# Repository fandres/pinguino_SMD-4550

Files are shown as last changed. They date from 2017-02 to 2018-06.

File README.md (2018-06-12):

This repository is possibly outdated
Este Repositorio se probablemente se encuentra desactualizado

Repository migrated to https://gitlab.com/fandres323/pinguino_SMD-4550
Repositorio migrado a https://gitlab.com/fandres323/pinguino_SMD-4550

# Pinguino SMD 4550

PCB in surface mount of the Pinguino board based on the microcontroller PIC18F4550 
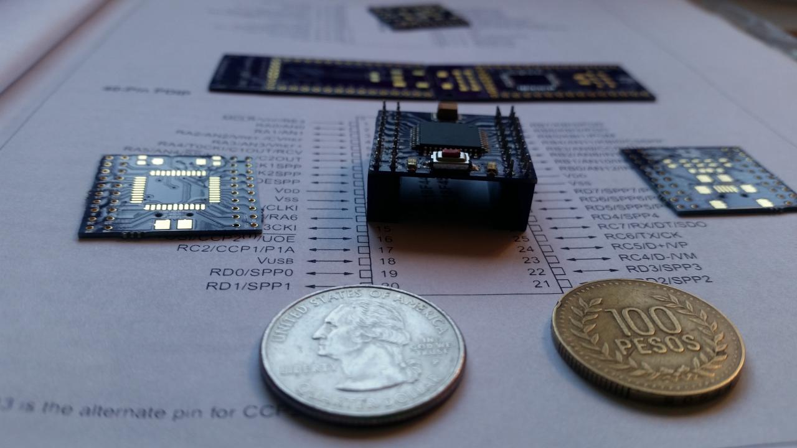
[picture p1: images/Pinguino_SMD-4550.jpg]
Pinguino_SMD-4550


## BOM 
Reference | Qty | Value | Footprint | Package
----- | ---------- | -------- | -------- | --------
C1 C2  | 2 | 22uF | Capacitors_SMD:C_0805 | 0805
C4  | 1 | 220nF | Capacitors_SMD:C_0805 | 0805
C3  | 1 | 100nF | Capacitors_SMD:C_0805 | 0805
C5  | 1 | 10-100uF | Capacitors_Tantalum_SMD:TantalC_SizeB_EIA-3528_Wave | B 3528
D1  | 1 | Run_LED | LEDs:LED_0805 | 0805
D2  | 1 | Power_LED | LEDs:LED_0805 | 0805
P1  | 1 | uUSB | Connect:USB_Mini-B | USB Female mini B 
P2 - P37 | 2 | Socket_Strips:Socket_Strip_Straight_2x10 | Female SIL 10x2 Pin
R2  | 1 | 10k | Resistors_SMD:R_0805 | 0805
R1 R3  | 2 | 470 | Resistors_SMD:R_0805 | 0805
SW1  | 1 | Reset | Buttons_Switches_SMD:SW_SPST_REED_CT05-XXXX-G1 | Sw SMD 1181
U1  | 1 | PIC18(L)F4550-I/PT | Housings_QFP:TQFP-44_10x10mm_Pitch0.8mm | TQFP-44
Y1  | 1 | Crystal | Crystal SMD:Crystal_SMD_5032_2Pads | 5032 2 Pads

# Order from OSH Park, $5 x3 



# Pinguino IDE

http://pinguino.cc/download.php

# Images
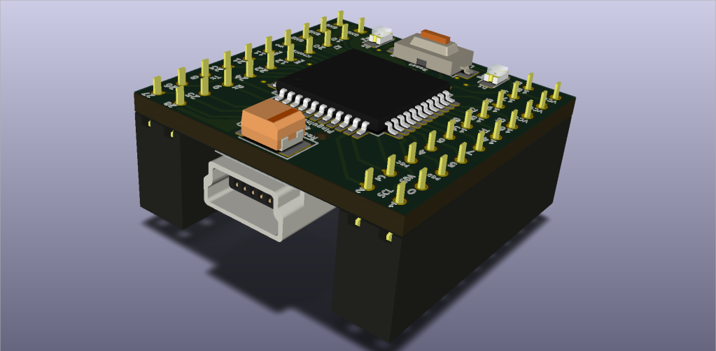
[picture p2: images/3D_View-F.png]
3DF_Pinguino_SMD-4550

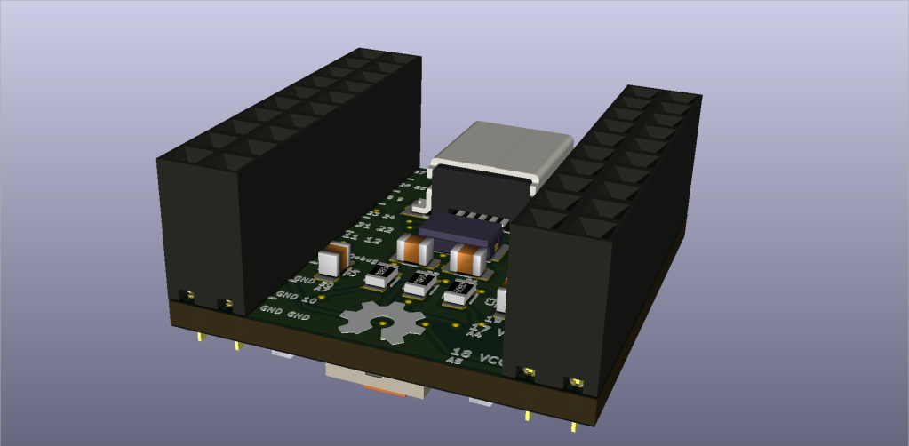
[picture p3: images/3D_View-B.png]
3DB_Pinguino_SMD-4550

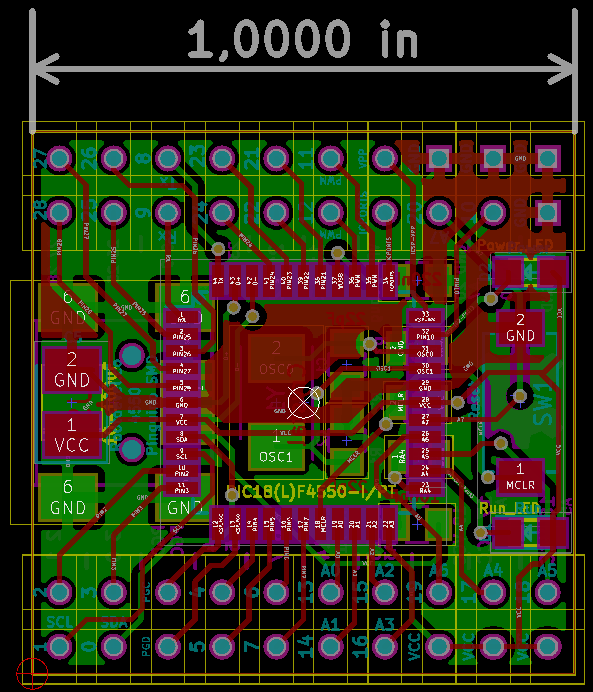
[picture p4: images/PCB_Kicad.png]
PCB_Pinguino_SMD-4550

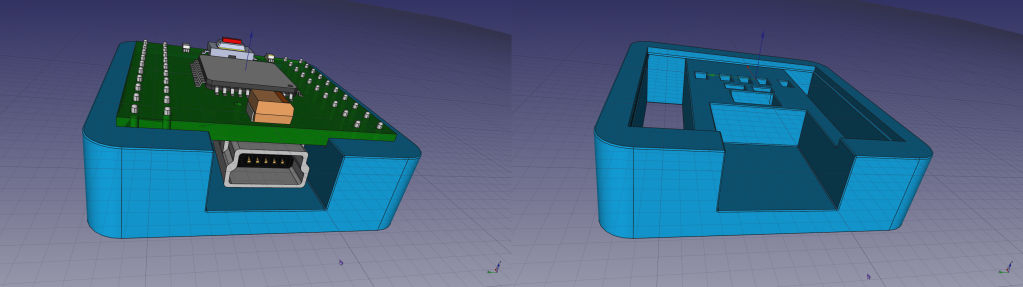
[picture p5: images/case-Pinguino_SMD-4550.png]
Cape_Pinguino_SMD-4550


# Attributions
<br /><span xmlns:dct="http://purl.org/dc/terms/" property="dct:title">Pinguino_SMD-4550</span> por <a xmlns:cc="http://creativecommons.org/ns#" href="https://github.com/fandres/pinguino_SMD-4550" property="cc:attributionName" rel="cc:attributionURL">Fabian Salamanca (fandres)</a> se distribuye bajo una <a rel="license" href="http://creativecommons.org/licenses/by-sa/4.0/">Licencia Creative Commons Atribución-CompartirIgual 4.0 Internacional</a>.<br />Basada en una obra en <a xmlns:dct="http://purl.org/dc/terms/" href="http://www.pinguino.cc/" rel="dct:source">http://www.pinguino.cc/</a>.

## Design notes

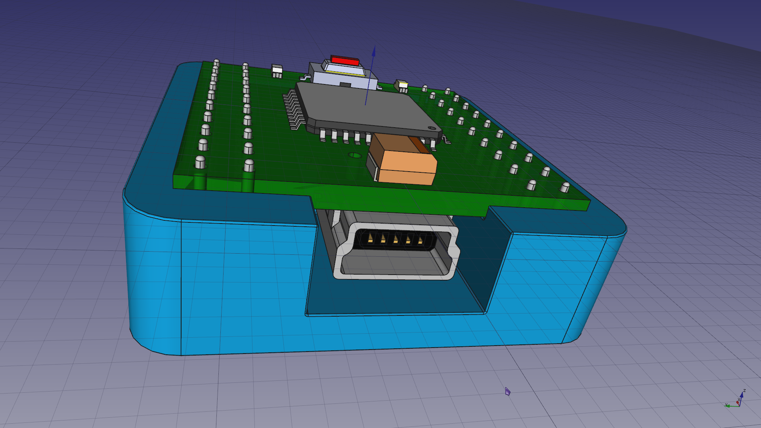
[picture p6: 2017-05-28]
images/case-Pinguino_SMD-4550.png_1.png

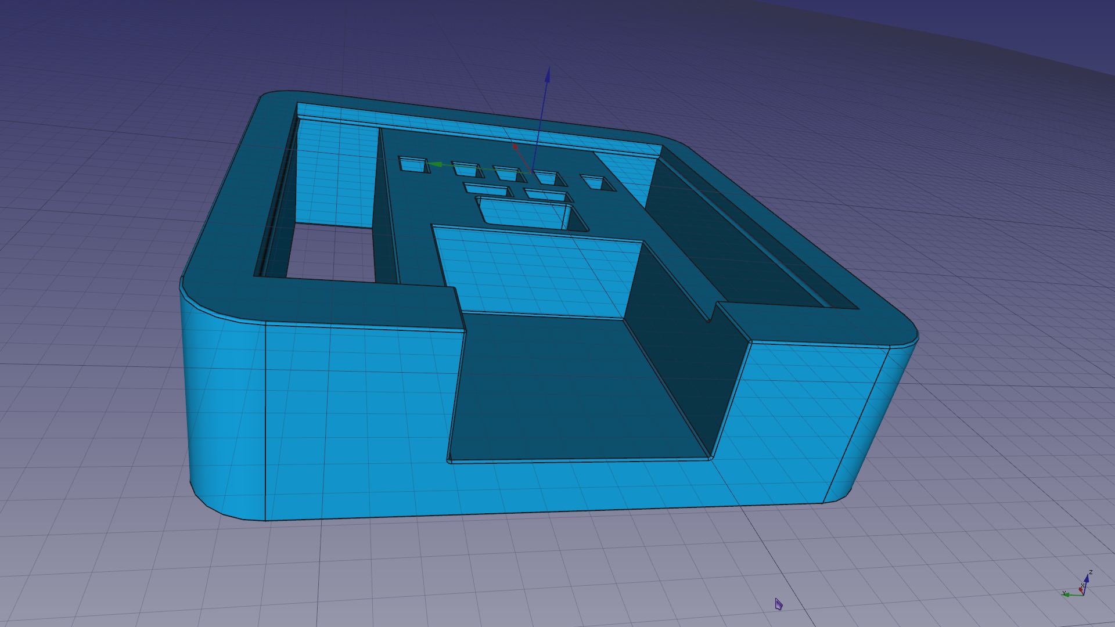
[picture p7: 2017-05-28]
images/case-Pinguino_SMD-4550.png_2.png

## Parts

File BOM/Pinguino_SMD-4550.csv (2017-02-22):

Title | Pinguino_SMD-4550
Revision | 1B
Date
Generated | mar 03 ene 2017 12:07:44 COT
Company | Rottdevel
Comment 1 | Hakerspace
Comment 2 | fAnDrEs
Comment 3
Comment 4
Total Parts | 51
Total Unique Parts | 13
Ref | Qty | Value | Footprint
C1 C2 | 2 | 22uF | Capacitors_SMD:C_1206
C4 | 1 | 220nF | Capacitors_SMD:C_1206
C3 | 1 | 100nF | Capacitors_SMD:C_1206
C5 | 1 | 10-100uF | Capacitors_SMD:c_elec_6.3x5.3
D1 | 1 | Run_LED | LEDs:LED_1206
D2 | 1 | Power_LED | LEDs:LED_1206
P1 | 1 | uUSB | Connect:USB_Mini-B
P6 P7 P9 P11 P13 P15 P17 P19 P21 P23 P25 P27 P29 P31 P33 P8 P10 P12 P14 P16 P34 P32 P30 P28 P26 P24 P22 P20 P18 P35 P36 P37 P4 P2 P5 P3 P38 | 37 | CONN_01X01 | Socket_Strips:Socket_Strip_Straight_1x01
R2 | 1 | 10k | Resistors_SMD:R_1206
R1 R3 | 2 | 470 | Resistors_SMD:R_1206
SW1 | 1 | Reset | Buttons_Switches_SMD:SW_SPST_REED_CT05-XXXX-G1
U1 | 1 | PIC18(L)F4550-I/PT | Housings_QFP:TQFP-44_10x10mm_Pitch0.8mm
Y1 | 1 | Crystal | Crystal SMD:Crystal_SMD_5032_2Pads
BOM made with KICAD_BOM_WIZARD (https://github.com/HashDefineElectronics/KiCad_BOM_Wizard.git)
Generated mar 03 ene 2017 12:07:44 COT

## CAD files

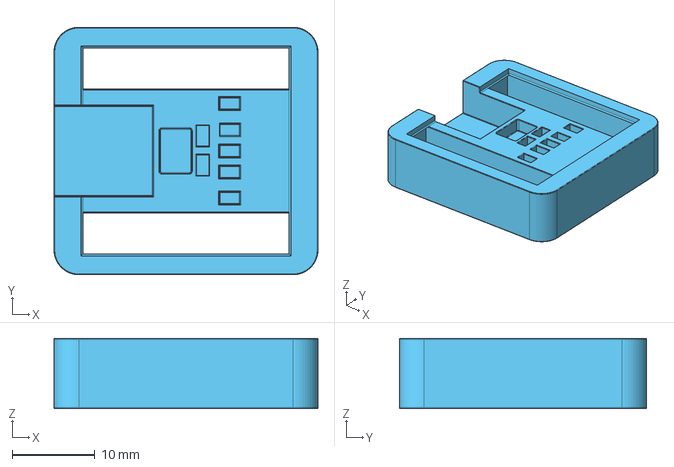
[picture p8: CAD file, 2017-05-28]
3D-Model/case-Pinguino_SMD-4550.step
32.0 x 30.0 x 8.50 mm

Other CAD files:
3D-Model/Pinguino_SMD-4550.step
3D-Model/Pinguino_SMD-4550.stl
3D-Model/Pinguino_SMD_4550.FCStd
3D-Model/case-Pinguino_SMD-4550.stl

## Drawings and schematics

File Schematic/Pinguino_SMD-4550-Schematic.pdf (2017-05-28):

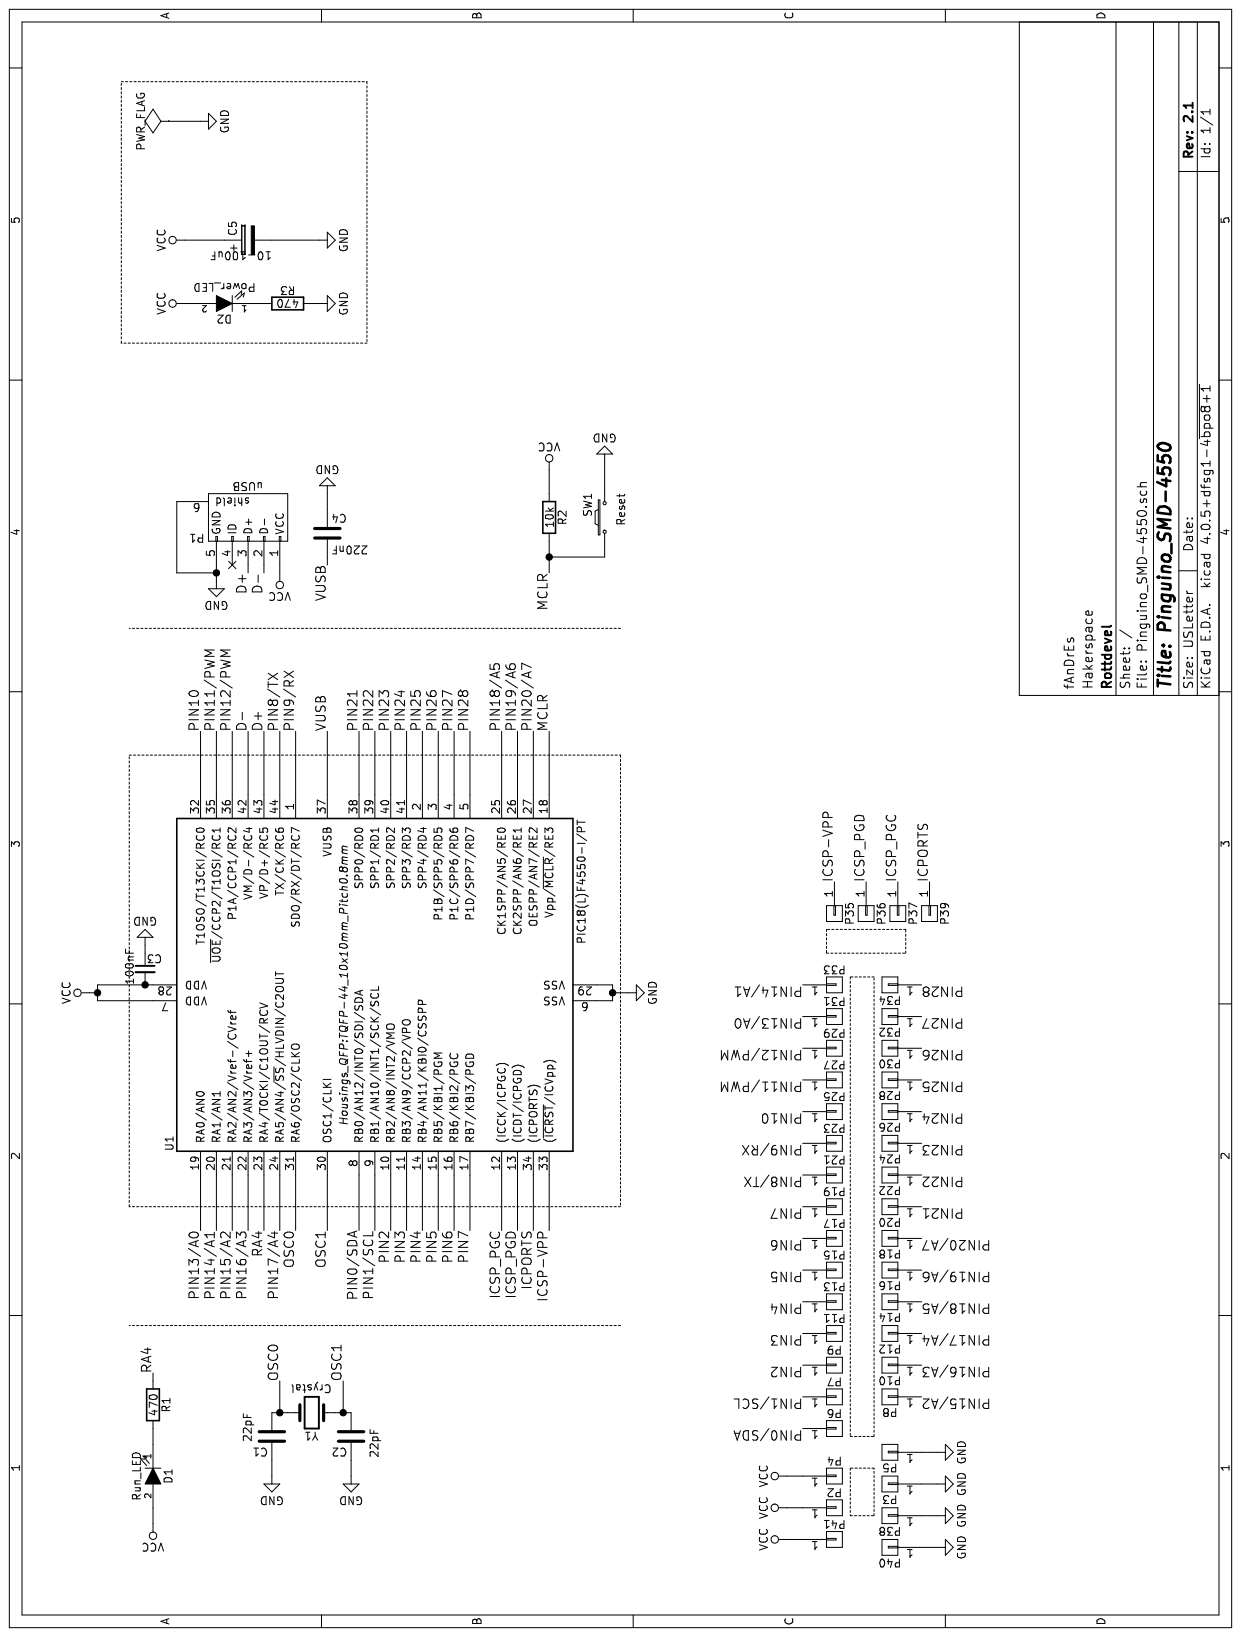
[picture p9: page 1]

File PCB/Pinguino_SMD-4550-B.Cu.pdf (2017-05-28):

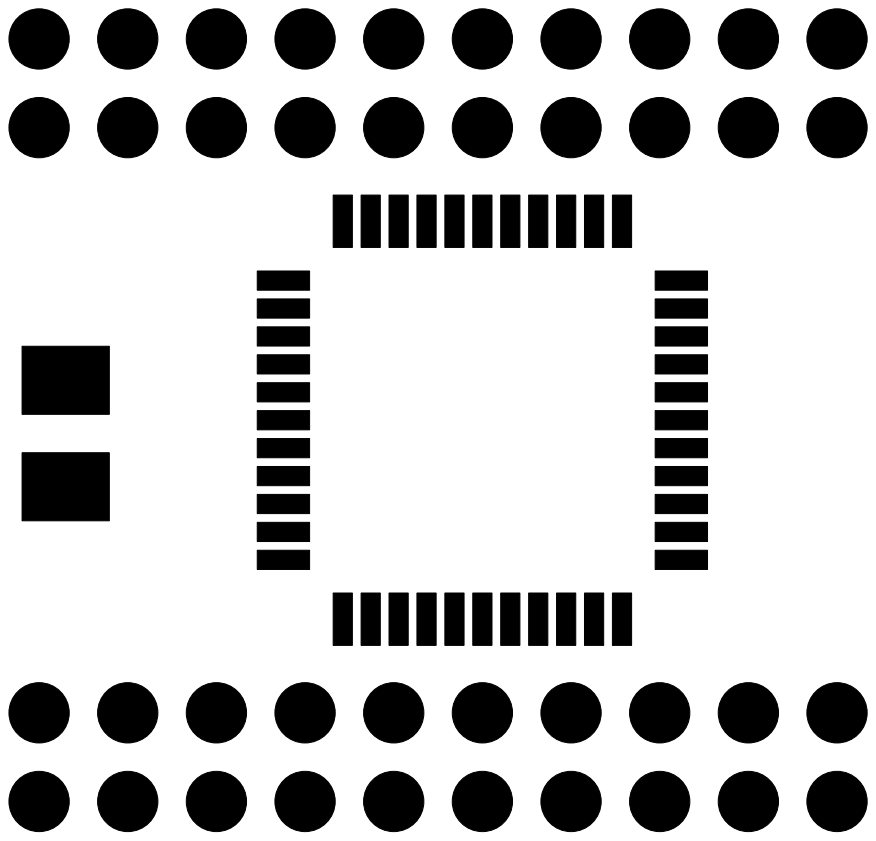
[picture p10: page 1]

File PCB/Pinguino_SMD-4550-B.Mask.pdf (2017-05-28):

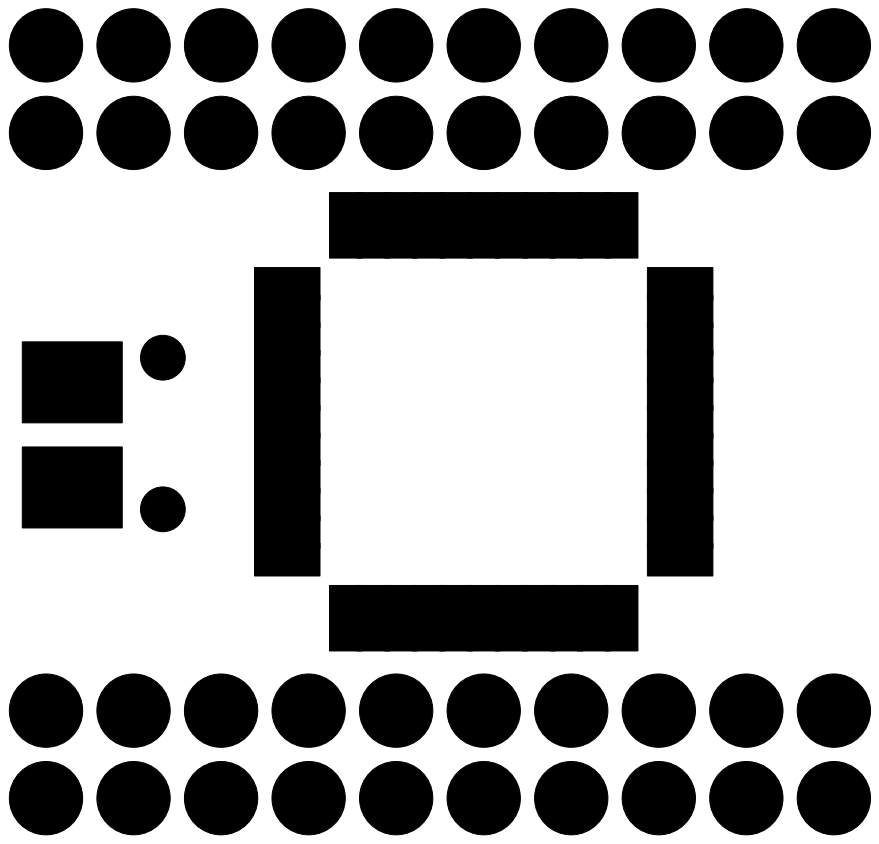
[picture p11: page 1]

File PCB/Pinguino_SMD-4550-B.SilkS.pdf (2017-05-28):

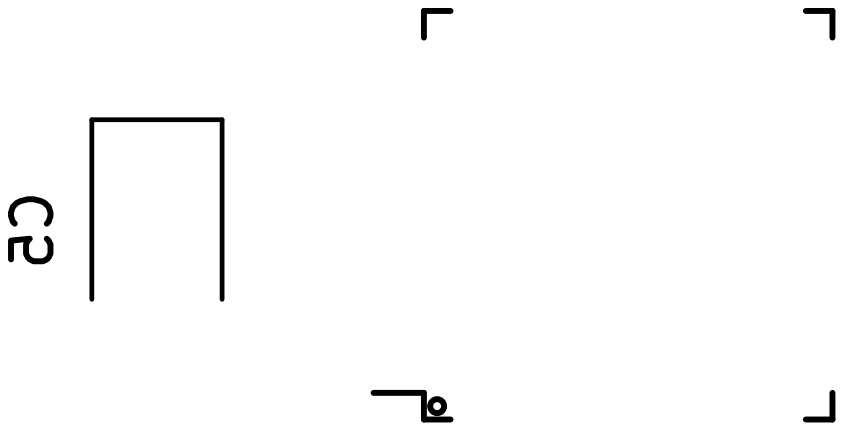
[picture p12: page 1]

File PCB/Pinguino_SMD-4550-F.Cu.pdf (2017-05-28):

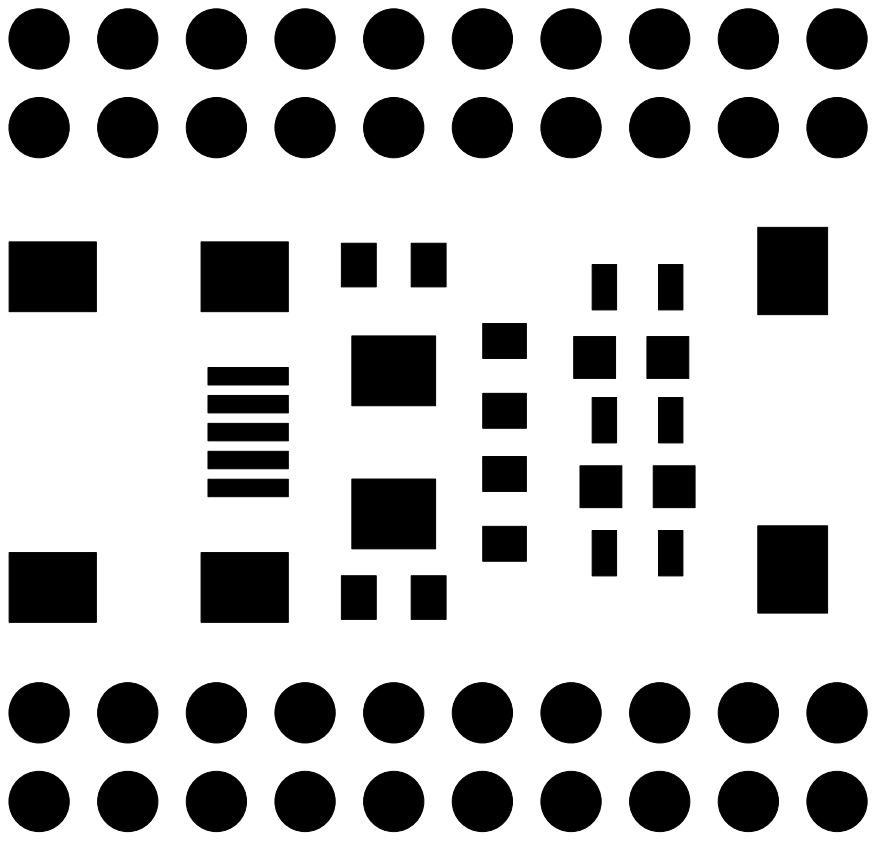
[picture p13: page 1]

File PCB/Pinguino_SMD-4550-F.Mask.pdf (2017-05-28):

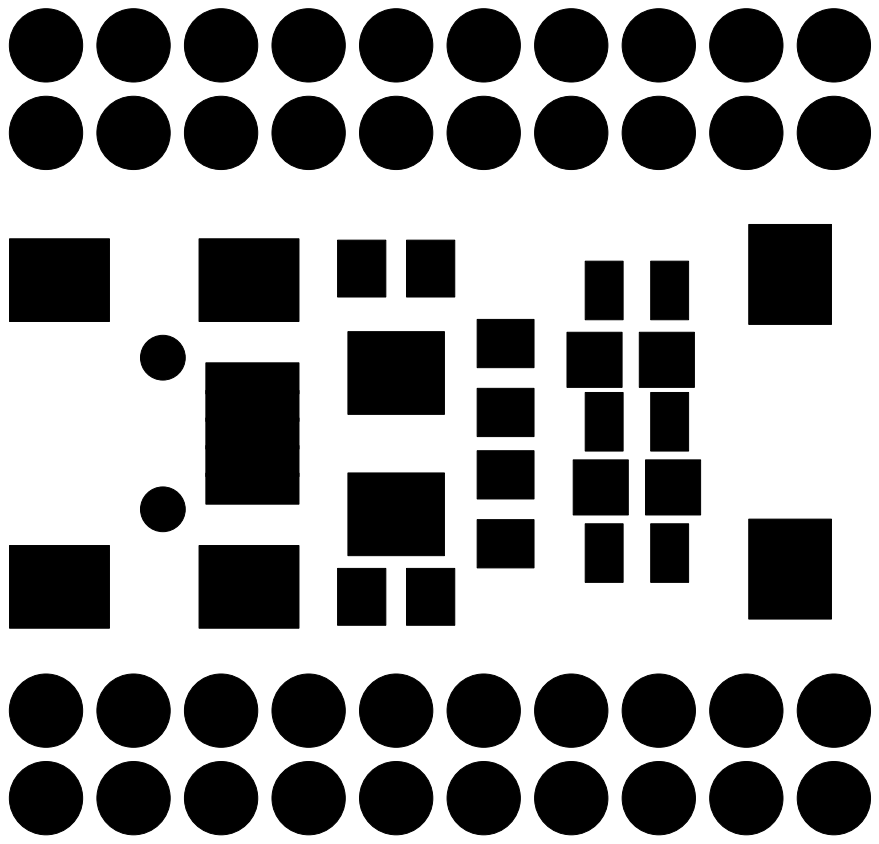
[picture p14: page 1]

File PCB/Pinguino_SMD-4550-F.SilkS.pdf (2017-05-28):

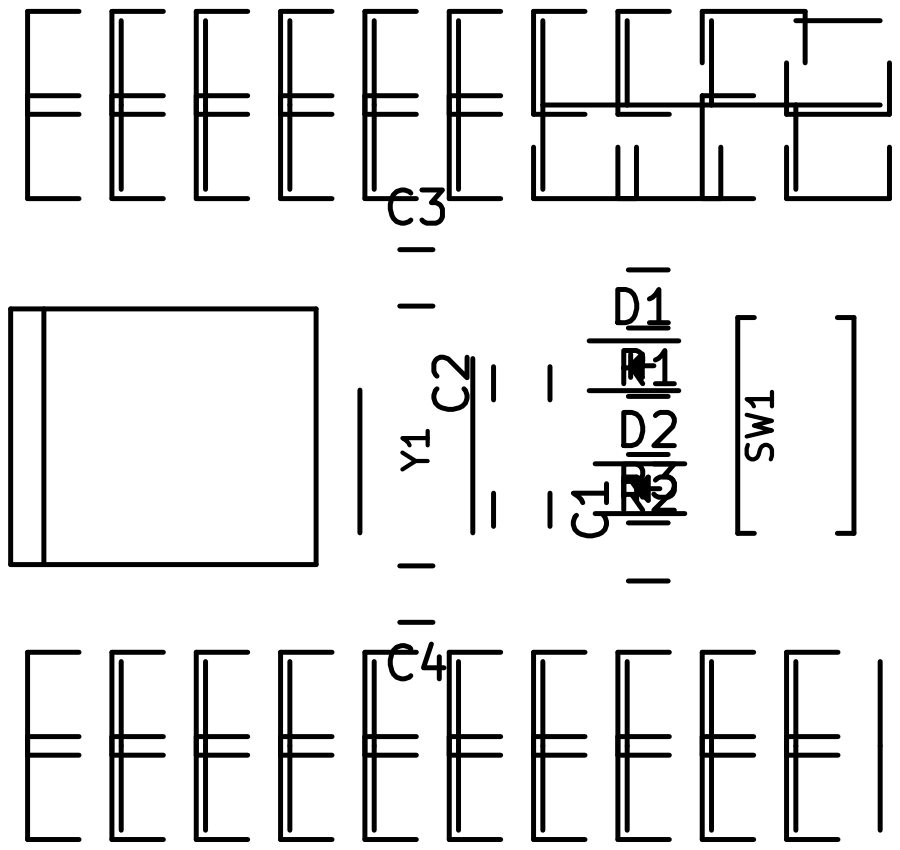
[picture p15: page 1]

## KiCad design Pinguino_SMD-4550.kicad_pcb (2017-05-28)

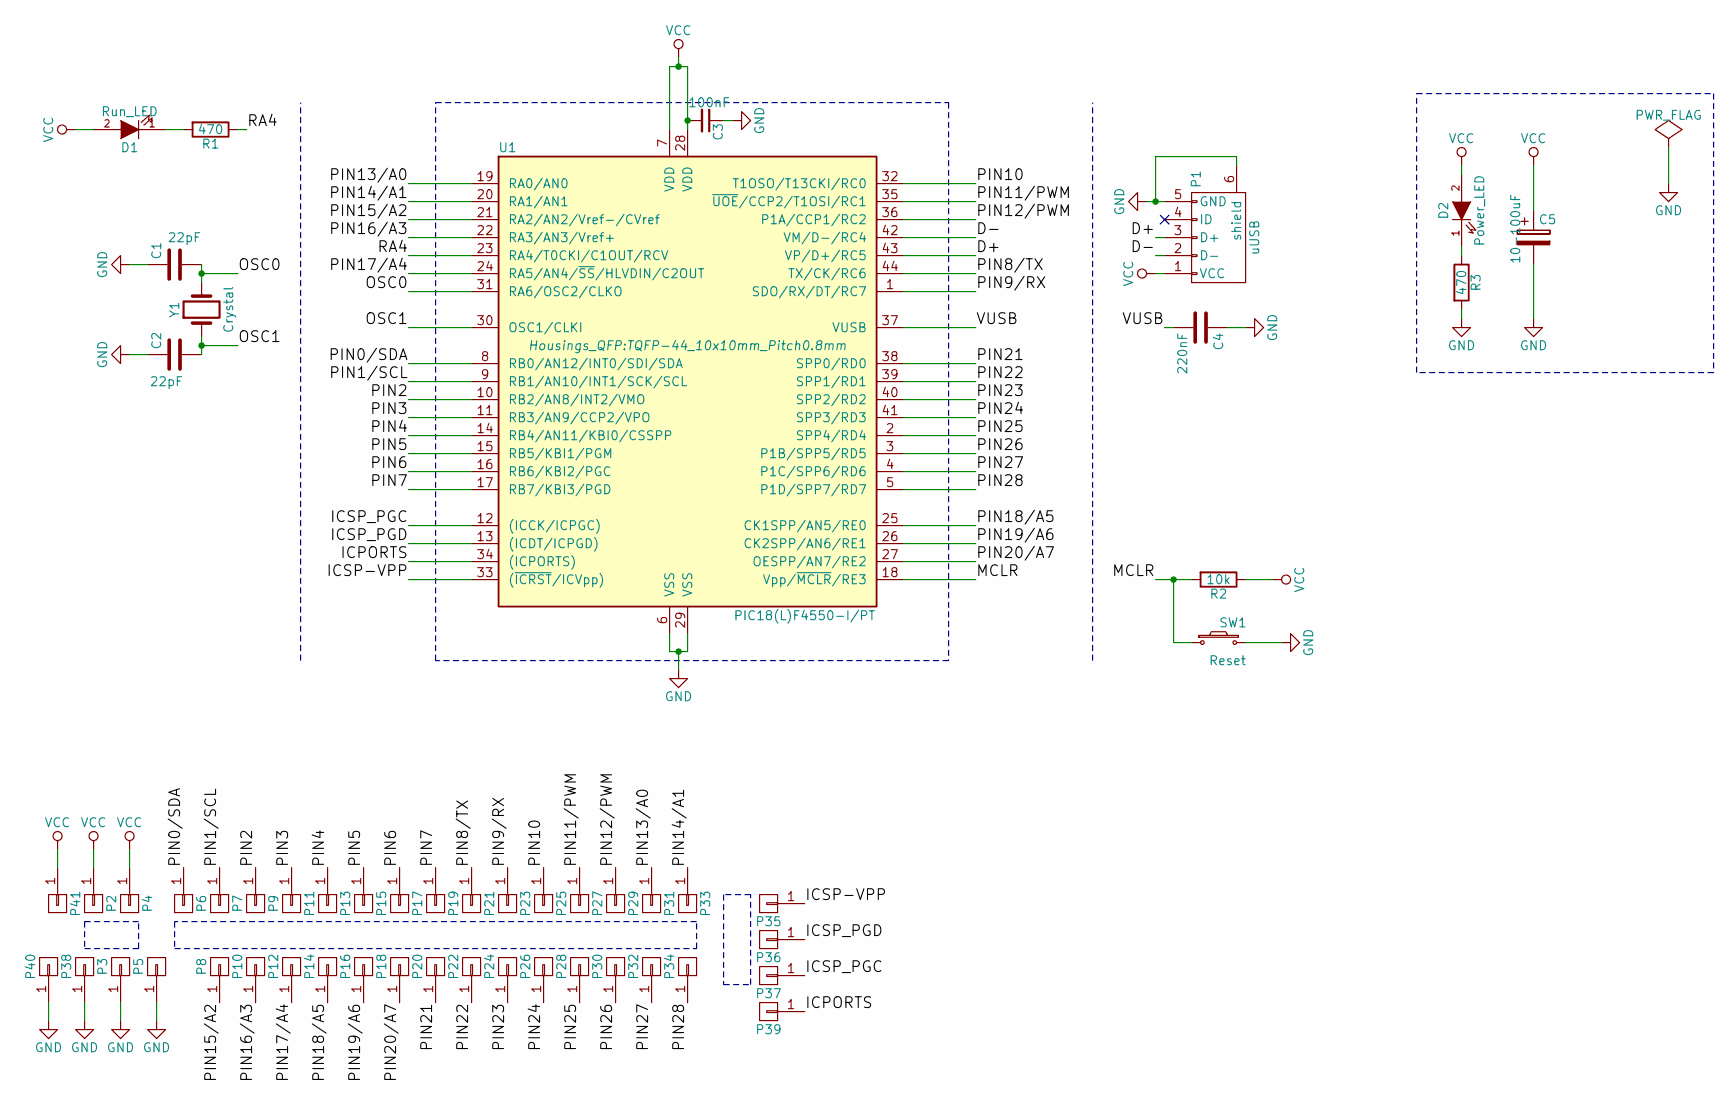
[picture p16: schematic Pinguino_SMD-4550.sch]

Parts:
C1, C2: 22pF; C_0805
C3: 100nF; C_0805
C4: 220nF; C_0805
C5: 10-100uF; CP_Tantalum_Case-B_EIA-3528-21_Reflow
D1: Run_LED; LED_0805
D2: Power_LED; LED_0805
P1: uUSB; USB_Mini-B
P2, P3, P4, P5, P6, P7, P8, P9, P10, P11, P12, P13, P14, P15, P16, P17, P18, P19, P20, P21, P22, P23, P24, P25, P26, P27, P28, P29, P30, P31, P32, P33, P34, P35, P36, P37, P38, P39, P40, P41: CONN_01X01; Socket_Strip_Straight_1x01
R1, R3: 470; R_0805
R2: 10k; R_0805
SW1: Reset; SW_SPST_REED_CT05-XXXX-G1
U1: PIC18(L)F4550-I/PT; TQFP-44_10x10mm_Pitch0.8mm
Y1: Crystal; Crystal_SMD_5032_2Pads

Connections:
/D+: P1.3 (D+), U1.43 (VP/D+/RC5)
/D-: P1.2 (D-), U1.42 (VM/D-/RC4)
/ICPORTS: P39.1, U1.34 ((ICPORTS))
/ICSP-VPP: P35.1, U1.33 ((~ICRST~/ICVpp))
/ICSP_PGC: P37.1, U1.12 ((ICCK/ICPGC))
/ICSP_PGD: P36.1, U1.13 ((ICDT/ICPGD))
/MCLR: R2.2, SW1.1, U1.18 (Vpp/~MCLR~/RE3)
/OSC0: C1.2, U1.31 (RA6/OSC2/CLKO), Y1.2
/OSC1: C2.2, U1.30 (OSC1/CLKI), Y1.1
/PIN0/SDA: P6.1, U1.8 (RB0/AN12/INT0/SDI/SDA)
/PIN1/SCL: P7.1, U1.9 (RB1/AN10/INT1/SCK/SCL)
/PIN2: P9.1, U1.10 (RB2/AN8/INT2/VMO)
/PIN3: P11.1, U1.11 (RB3/AN9/CCP2/VPO)
/PIN4: P13.1, U1.14 (RB4/AN11/KBI0/CSSPP)
/PIN5: P15.1, U1.15 (RB5/KBI1/PGM)
/PIN6: P17.1, U1.16 (RB6/KBI2/PGC)
/PIN7: P19.1, U1.17 (RB7/KBI3/PGD)
/PIN8/TX: P21.1, U1.44 (TX/CK/RC6)
/PIN9/RX: P23.1, U1.1 (SDO/RX/DT/RC7)
/PIN10: P25.1, U1.32 (T1OSO/T13CKI/RC0)
/PIN11/PWM: P27.1, U1.35 (~UOE~/CCP2/T1OSI/RC1)
/PIN12/PWM: P29.1, U1.36 (P1A/CCP1/RC2)
/PIN13/A0: P31.1, U1.19 (RA0/AN0)
/PIN14/A1: P33.1, U1.20 (RA1/AN1)
/PIN15/A2: P8.1, U1.21 (RA2/AN2/Vref-/CVref)
/PIN16/A3: P10.1, U1.22 (RA3/AN3/Vref+)
/PIN17/A4: P12.1, U1.24 (RA5/AN4/~SS~/HLVDIN/C2OUT)
/PIN18/A5: P14.1, U1.25 (CK1SPP/AN5/RE0)
/PIN19/A6: P16.1, U1.26 (CK2SPP/AN6/RE1)
/PIN20/A7: P18.1, U1.27 (OESPP/AN7/RE2)
/PIN21: P20.1, U1.38 (SPP0/RD0)
/PIN22: P22.1, U1.39 (SPP1/RD1)
/PIN23: P24.1, U1.40 (SPP2/RD2)
/PIN24: P26.1, U1.41 (SPP3/RD3)
/PIN25: P28.1, U1.2 (SPP4/RD4)
/PIN26: P30.1, U1.3 (P1B/SPP5/RD5)
/PIN27: P32.1, U1.4 (P1C/SPP6/RD6)
/PIN28: P34.1, U1.5 (P1D/SPP7/RD7)
/RA4: R1.1, U1.23 (RA4/T0CKI/C1OUT/RCV)
/VUSB: C4.2, U1.37 (VUSB)
GND: C1.1, C2.1, C3.1, C4.1, C5.2, P1.5 (GND), P1.6 (shield), P3.1, P5.1, P38.1, P40.1, R3.2, SW1.2, U1.6 (VSS), U1.29 (VSS)
unnamed: D1.1 (K), R1.2
unnamed: D2.1 (K), R3.1
VCC: C3.2, C5.1, D1.2 (A), D2.2 (A), P1.1 (VCC), P2.1, P4.1, P41.1, R2.1, U1.7 (VDD), U1.28 (VDD)

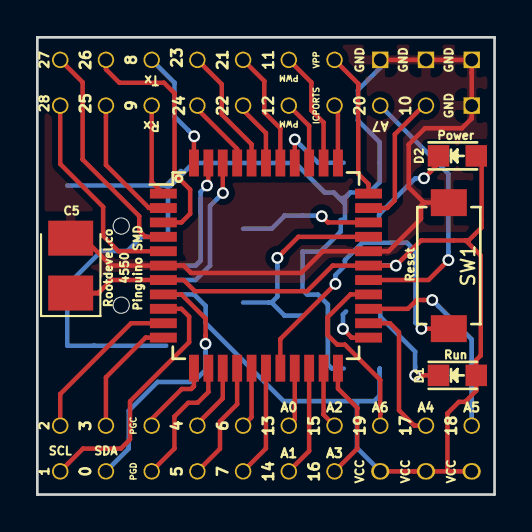
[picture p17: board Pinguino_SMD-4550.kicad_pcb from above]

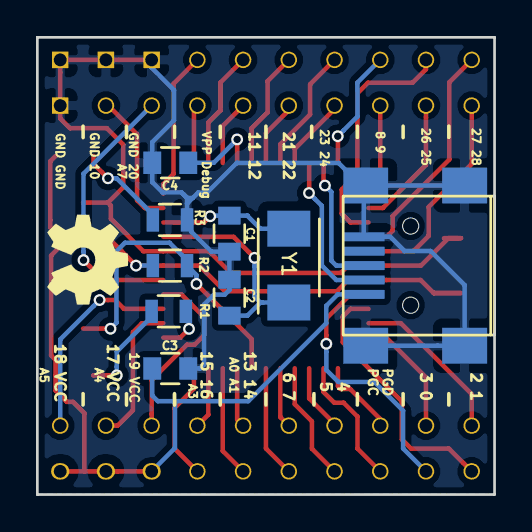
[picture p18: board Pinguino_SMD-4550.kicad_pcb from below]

Board: 2 copper layers, 25.4 x 25.4 mm, 54 parts (49 on the bottom side), 44 nets.

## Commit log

2016-12-22 Upload Projec files; Esquema + Componentes asociados (CvPcb)
    [Pinguino_SMD-4550.kicad_pcb, Pinguino_SMD-4550.sch]
2016-12-28 Reorganized and aligned components. Capapol -> Tantalum B 3528.
    [Pinguino_SMD-4550.kicad_pcb, Pinguino_SMD-4550.sch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]
2016-12-29 Fixed error: VCC -> Pin 28, GND -> C3. Autoruting
    [Pinguino_SMD-4550.dsn, Pinguino_SMD-4550.kicad_pcb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]
2016-12-31 Tracks improvement
    [Pinguino_SMD-4550.kicad_pcb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]
2016-12-31 Added zones (F.cu, B.cu)
    [Pinguino_SMD-4550.kicad_pcb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]
2017-01-03 Silkscreen layers
    [Pinguino_SMD-4550.kicad_pcb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]
2017-01-03 Added BOM and modified README.md
    [Pinguino_SMD-4550.csv, Pinguino_SMD-4550.kicad_pcb, Pinguino_SMD-4550.sch]
2017-01-04 Model 3D: Board
    [Pinguino_SMD-4550.kicad_pcb, Pinguino_SMD-45501.stl, Pinguino_SMD_4550.FCStd]
2017-01-04 Fixed bug: STL
    [Pinguino_SMD-45501.stl]
2017-01-05 Model 3D: Case
    [Pinguino_SMD-4550.kicad_pcb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]
2017-01-05 Added image: Case
    [Pinguino_SMD-4550.step, Pinguino_SMD-45501.step, case-Pinguino_SMD-4550.step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]
2017-02-22 Fixed Silkscreen and others. Modified readme.md file. Add Licence
    [Pinguino_SMD-4550.kicad_pcb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]
2017-02-22 Reorganized and aligned components.
    [Pinguino_SMD-4550.kicad_pcb, Pinguino_SMD-4550.sch, Pinguino_SMD-4550.step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]
2017-02-22 Generate gerber
2017-02-22 Fixed info: capa-e
    [Pinguino_SMD-4550.csv]
2017-02-22 Resized Throug Hole Pads
    [Pinguino_SMD-4550.kicad_pcb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]
2017-02-22 Autoruting1, Reorganized Componets
    [Pinguino_SMD-4550.kicad_pcb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]
2017-02-22 Autoruting2, Reorganized Componets
    [Pinguino_SMD-4550.dsn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]
2017-02-22 Tracks and Vias improvement
    [Pinguino_SMD-4550.kicad_pcb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]
2017-02-22 Added zones (F.cu, B.cu -> GND)
    [Pinguino_SMD-4550.kicad_pcb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]
2017-02-24 Model 3D: Case 4550
    [Pinguino_SMD_4550.FCStd, case-Pinguino_SMD-4550.step, case-Pinguino_SMD-4550.stl]
2017-02-27 Silkscreen layes: Logos
    [Pinguino_SMD-4550.kicad_pcb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]
2017-04-09 F.Fab, B.Fab
    [Pinguino_SMD-4550.kicad_pcb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]
2017-05-27 Bug Fixed: RA4
    [Pinguino_SMD-4550.kicad_pcb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]
2017-05-28 Added image
    [Pinguino_SMD-4550.kicad_pcb]
